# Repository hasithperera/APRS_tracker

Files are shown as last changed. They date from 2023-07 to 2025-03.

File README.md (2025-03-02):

# APRS_tracker

Standalone APRS tracker. This an Arduino-nano powered APRS tracker with a DRA818V 1 W radio module.

## Progress

- Fully functional PCB(v2) - tested up to 11 km in a HAB flight
- Basic full operation was tested with the board externally powered. Refer the test section for details.
- v3: Nearly complete PCB with new GPS module
	- level shifter externally added using a 7404 

### Firmware

- [x] Bug fix for location packets
- [x] Support for GNSS GPS (Adafruit GPS) ✅ 2024-01-28
- [x] Added support for i2c for external data sources ✅ 2024-01-28
## Testing 

In order to make sure the full functionality the generated APRS packets were tested with [direwolf](https://github.com/wb2osz/direwolf) with a RTL-SDR.
The following command was used to run the iGate

``` rtl_fm -f 144.39M - |direwolf -c sdr.conf -r 24000 -D 1 - ```

- The radio tx frequency commands were tested on a simplex 145.390 M and the standard 144.390 M
- A ground test was carried out on 05/14/23.
	- Device was powered with a external 5V USB power bank for the duration of the test
	- initial GPS lock was completed within 30 s of powering on outside.
	- It was noted that powering indoor and moving to an outdoor location increased the initial GPS lock time significantly.
	- Data collected is available online under the call sign KC3RXZ. a screenshot can be found below. Note that not all the packets were captured by the iGate and the msg_id was used as a counter for how many GPS packets were captured during the test period.Given that the iGate was located indoor and the landscape of the location could account for the lost packets.

APRS ground testing.

### Flight testing

- First HAB flight on 01/10/2023
- call: KE8TJE-11
- data: [aprs.fi](https://aprs.fi/#!mt=roadmap&z=10&call=a%2FKE8TJE-11&timerange=21600&tail=21600)
- comments: The GPS module used worked well up to 11 km of altitude. above that it was unusable
- more information available [here](https://docs.google.com/presentation/d/1fhy-rmdOGR4Q17i7Nnw9TJokxQfwU8tR1A3V_ZNNeEo/edit?usp=sharing) including flight data

## Updates to the PCB

### update: 05/07/23

- [x] Update PCB based on v1.
- know minor issues
	- jumpers on the board need to be larger

### update: October 2023

- updated the GPS module

![aprs_v3](doc/reports/res/aprs_v3.png)

### update: January 2034
- New design with an expansion slot to connect external modules.
- A DTMF decoder board is been developed.
- [ ] Final integration testing needs to be done

## Todo list 

- [x] interface GPS sensor
- [x] interface RF
- [x] APRS generation
- [x] get location and update APRS data packet
- [x] i2c slave module to provide data to master ✅ 2024-01-28
- [x] field testing 
- [x] finalized PCB design 
- [x] long range testing at altitude

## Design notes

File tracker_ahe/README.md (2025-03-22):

# APRS Tracker - customization 

Most common settings are set up as `#define` statements for easy configuration. Some of the major settings are listed below with their typical value

variable | value | note 
---| --- | --- | 
myCALL[] |  | Change to your callsign
APRS_TX_offset_utc_sec  | 19 | UTC second the packet is sent out
aprs_id | 11 | station id used for aprs

## Programming the firmware

You need to have avrdude installed on your local computer along with an USBasp programmer. 

Using arduino you can export the `hex` file by using Sketch > Export compiled Binary. A new folder `build` will be created which contains the hex file needed.
To program the APRS board use the following command. 

`avrdude -p m328p -c usbasp -U flash:w:tracker_ahe.ino.hex`

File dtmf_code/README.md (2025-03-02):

- This is an expansion board designed to be connected to the `v4` board
- Based on an ATTINY 84
- An i2c master will be running in order to sent data to the APRS board

## Audio performance 

- lab testing with 50 mW signal indicated limited functionality on the DTMF digits. Digits 7,8,9,0,#,* was confirmed to be working. a 620k is tested for the amplification
- It was noted the extended wire length induced RF and cause the signals to be unusable
	- 330 K and the build in 500 K pot was more than enough tuning range

## i2c 

- [ ] Send data to multiple addresses
- [ ] Request data from slave.  📅 2024-02-06 

## old - Docs

DTMF - Test

# To-do

- [x] i2c master sending data ✅ 2024-01-28
- [ ] i2c master reading data from slaves
- [x] Evaluate the RF/Audio performance at altitude ✅ 2024-01-29

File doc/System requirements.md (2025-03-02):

This contains the final system requirements for the system

- The user shall be able to turn on the payload
- The user shall be able to turn off the payload
- The system shall initialize the RF and GPS subsystems
- The system shall provide indicators for GPS lock,RF inputs (via DTMF)
- The system shall send location packets via APRS packets
- The system shall send DTMF, GPS time via i2c to specified slave device connected.
- The system shall burn cutdown wires upon DTMF command
- The system shall burn recovery wire at set altitude

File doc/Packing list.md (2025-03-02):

- [ ] Science payload
	- [ ] Battery 
	- [ ] Enclosure
	- [ ] Cut down string

- [ ] Recovery vehicle
	- [ ] Laptop
	- [ ] Charger
	- [ ] GPS + SDR
	- [ ] USB extension cable
	- [ ] antenna for SDR
	- [ ] Emmcomm kit for radio
	- [ ] Adapters for antennas 
	- [ ] HT - for low power testing 

## Testing to be done and time line

- [ ] Full cut-down testing in lab. verify pin `789`
- [ ] Confirm data write to SD card
	- [ ] i2c command log
	- [ ] GPS data log

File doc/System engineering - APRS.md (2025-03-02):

# APRS payload - Concept

 ## Need
- To track rockets during descent and help recovery by identifying the location after landing

## Stake holders
- Rocketry control system 
- FCC 
- Additions due to NEBP
	- NEBP & WVBEAR -  (Added as an alternate user after the initial design)
	- FAA
	- Science Payload (Addition after PAGSO grant acceptance)

---
## Constraints 

- Weight:
	- Based on the specification of NEBP payload design 350 g
- Physical Dimensions:
	- need to be able to fit inside a 3.5 inch rocket. 
	- Have a thermal insulation (High altitude use - NEBP)
- Operational altitude
	- 10 km - from Rocketry
	- 30 km - from NEBP HAB requirements 
- Power -  5v (2s Li-ion/Li-Po)
- Standalone and paired operation modes
- FCC requirements: [47 CFR 97.307(e)](https://www.ecfr.gov/current/title-47/part-97#p-97.307(e))
	- data down link. (uplink added as a Science requirement)

---
# Use case diagram - Rocketry

UML_1

---
# Use case diagram - NEBP

UML_2

---

# Use case diagram - NEBP + Science

UML_3

---
# Logical architecture 

logical

---
## Interface specifications

- RF IF
	- **Data down link:** 144.390 MHz AX 2.5 encoded data stream every 5 mins
		- Have a secondary frequency for high cadence data 
	- **Up link**: some random frequency for each payload using DTMF commands
- i2c IF
	- DTMF and GPS time data will be sent to slave devices
		- Commands:  upto 20 digits can be stored and sent as a single char array. shorter commands can be defined using the `#` as the termination char.
		- GPS time: 3 8 bit integers containing hh,mm,ss in that order
---
## Interface specifications - 2

- Physical IF
	- the payload will be physically connected to the flight line with **Micro code** up to a length of 1 ft.
	- These will be routed through a burn wire
- Power IF
	- 7.4 V Li-Ion cells
	- a shared 5 V regulated supply up to 800 mA

---
# Final system requirements

- The user shall be able to turn on the payload
- The user shall be able to turn off the payload
- The system shall initialize the RF and GPS subsystems
- The system shall provide indicators for GPS lock,RF inputs (via DTMF)
- The system shall send location packets via APRS packets
- The system shall send DTMF, GPS time via i2c to specified slave device connected.
- The system shall burn cutdown wires upon DTMF command
- The system shall burn recovery wire at set altitude

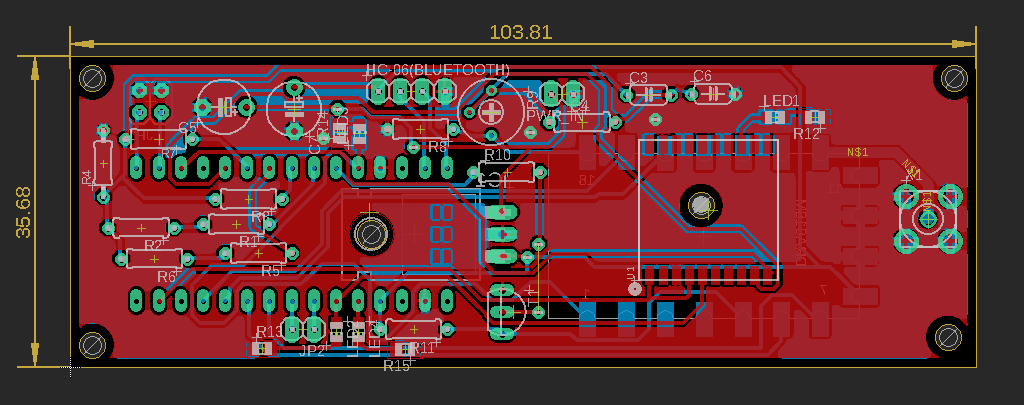
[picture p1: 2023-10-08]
doc/reports/res/aprs_v3.png

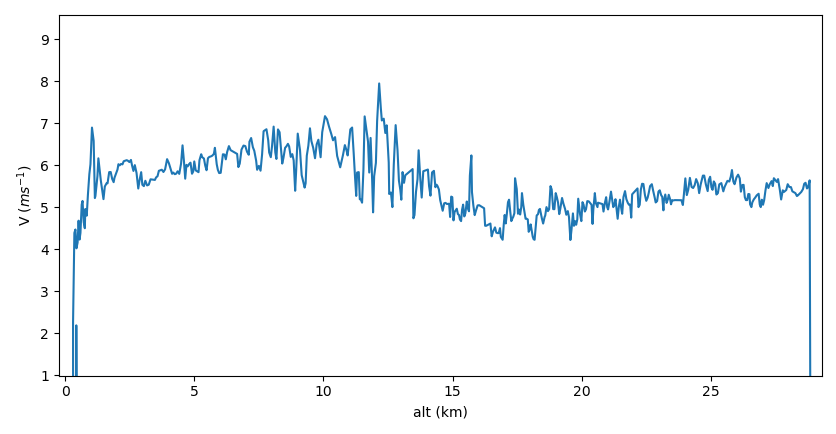
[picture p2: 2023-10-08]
doc/reports/res/v_alt_NEBP2.png

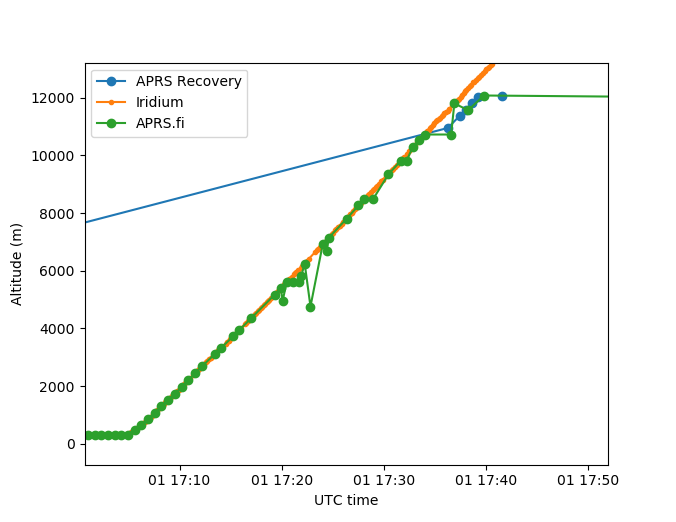
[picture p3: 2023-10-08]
doc/reports/res/01_10_23_altitude_ascent_data.png

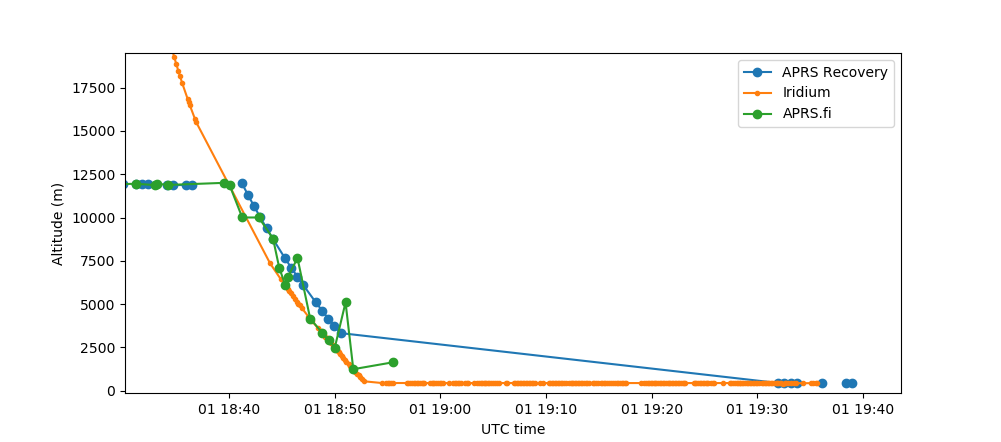
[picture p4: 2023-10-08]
doc/reports/res/01_10_23_altitude_dsc_data.png

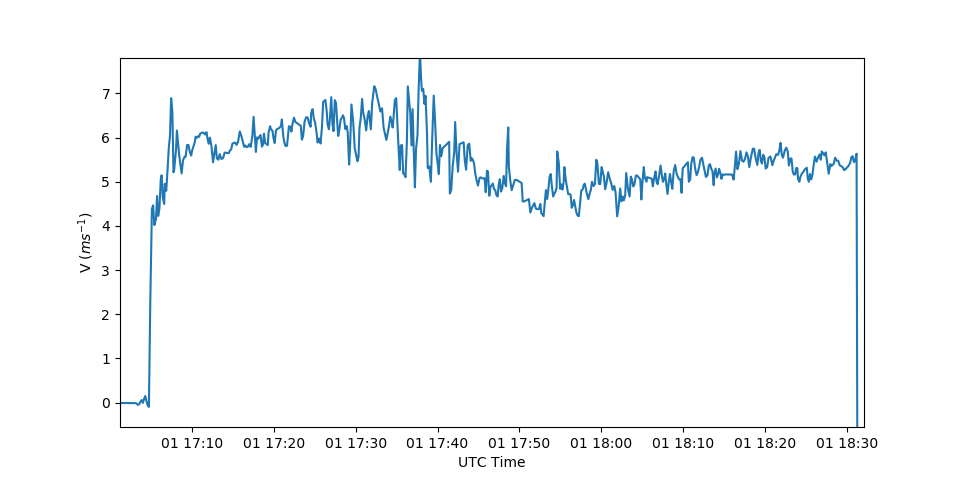
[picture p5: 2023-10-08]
doc/reports/res/v_t_NEBP2.png

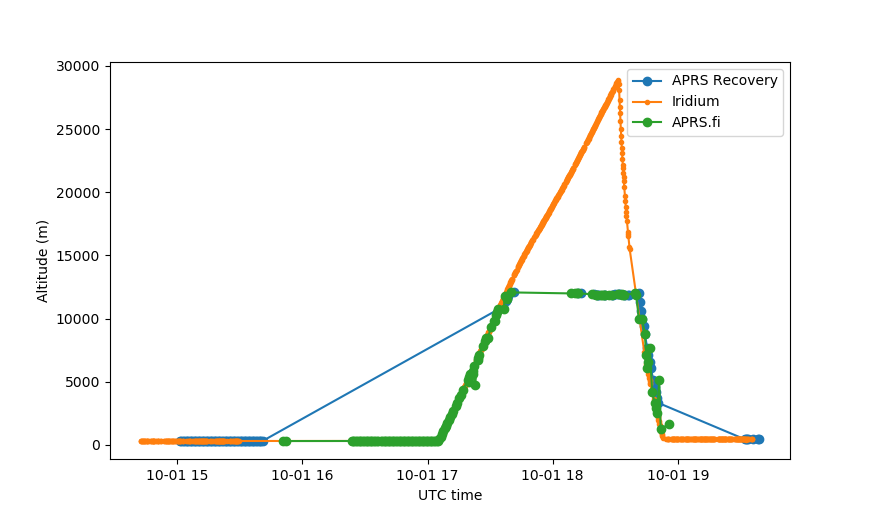
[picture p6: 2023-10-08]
doc/reports/res/01_10_23_altitude_data.png

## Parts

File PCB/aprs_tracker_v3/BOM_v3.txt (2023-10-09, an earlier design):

Partlist

Exported from aprs_tracker_v3.brd at 10/9/23 8:44 AM

EAGLE Version 9.6.2 Copyright (c) 1988-2020 Autodesk, Inc.

Assembly variant: 

Part             Value          Package       Library       Position (mil)        Orientation

C3               4.7u           C050-024X044  rcl           (2610 1230)           R0
C4               4.7u           C1206         rcl           (2609.37008 1325)     R0
C5               10u            E5-6          rcl           (695 1175)            R180
C6               100n           C050-024X044  rcl           (2900 1235)           R0
C7               10u            E5-6          rcl           (1010 1165)           R270
HC-06(BLUETOOTH)                1X04          pinhead       (1540 1245)           R0
IC1              7805T          TO220H        adafruit      (1550 600)            MR270
JP1                             2X02          pinhead       (360 1200)            MR180
JP2                             1X02          pinhead       (1050 170)            R180
LED1                            CHIP-LED0805  led           (3180 1130)           R270
LED2                            CHIP-LED0805  led           (1200 160)            R180
LED3                            CHIP-LED0805  led           (1305 1055)           R0
LED4                            CHIP-LED0805  led           (1300 160)            R180
PWR_IN                          1X02          pinhead       (2259.37008 1235)     R180
R1               6.2k           0207/7        rcl           (750 645)             R180
R2               2k             0207/7        rcl           (320 630)             R180
R3               3.9k           0207/7        rcl           (805 760)             R180
R4               270            0204/7        rcl           (150 920)             R90
R5               1.2k           0207/7        rcl           (850 515)             R180
R6               1k             0207/7        rcl           (380 490)             R180
R7               1k             0207/7        rcl           (400 1030)            R180
R8               1k             0207/7        rcl           (1580 1075)           R180
R9               1k             RTRIM3339P    rcl           (1930 1160)           R270
R10              1k             0207/7        rcl           (1970 880)            R0
R11              1k             0207/7        rcl           (1550 170)            R180
R12              330            R0805         rcl           (3360 1130)           R180
R13              330            R0805         rcl           (865 85)              R0
R14              330            R0805         rcl           (1215 1060)           R90
R15              330            R0805         rcl           (1510 80)             R180
T1               2N2222         TO92-EBC-OVAL adafruit      (2000 250)            R270
U$1                             DRA818A       dorji         (2855 590)            MR90
U$4              NANO-2         NANO-NOICSP   Arduino-clone (1350 700)            R90
U1                              FGPMMOPA6H    adafruit      (2880 710)            R90
X1               BU-SMA-V       BU-SMA-V      con-coax      (3870 670)            R0

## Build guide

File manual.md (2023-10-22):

# Offline ground station and Tracker manual

## Tracker configuration 

- current configuration: These settings needs to be set by reprogramming and current settings are indicated 
	- call sign: KE8TJE-11
  - beacon time: ~40 

internally on the PCB there are two configuration pins available for testing

- pin 1: frequency selection (0: 144.390 M 1: 145.390 M) 
- pin 2: location data (1: sim data 0: GPS data)

## Ground station configuration

- Run `rtl-test` to check if the SDR is working 
- `rtl_fm -f 144.39M - |direwolf -c sdr.conf -r 24000 -D 1 - >> log_sdr.log`
- run for visualization `java -jar YAAC.jar`

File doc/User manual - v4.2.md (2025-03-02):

- Use `v4.2` this is found in the `dtmf` branch on the repository.
## Confirm APRS opetation

- By default this is design for a ~30 s update rate on the 144.390 MHz standard APRS frequency in the US.
- There are two use configurable jumpers available for testing:
	
	- JP1 can be used to change the frequency to an alternate frequency.
	- JP2 can be used to enable simulation mode. This allows indoor testing on the module without GPS lock

- Onboard LEDs
	- D1: GPS serial Rx
	- D2: GPS serial Tx
	- D3: 3D GPS lock
	- D4: RF channel busy indicator active low. (Rx frequency is set to 146.800 MHz)
	- D5: Power indicator
### Simulation mode

- Connect a jumper to JP2. This will populate GPS data with a valid data packet located in Morgantown WV. (location ) verify the APRS data is correctly encoded in your preferred decoding software

### Debug data via serial terminal

- In addition to readable status comment the `$GNGGA` packets are redirected to the serial terminal when not in simulation mode
- When there is GPS lock decoded Longitude and Latitude is made available to the user.
	- `3938.76N,07958.44W`
- Sample terminal out put during simulation mode
  
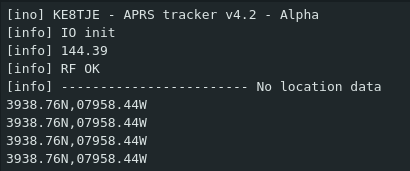
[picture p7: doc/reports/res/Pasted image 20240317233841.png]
	

## DTMF commanding

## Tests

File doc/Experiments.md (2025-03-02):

## OTA
- 57600 BAUD did not seem to work to program the arduino.
- It could be due 
	- reset pin not being correctly configured with the voltage levels
	- baud rate used may not be correct 

## Ground testing - v4

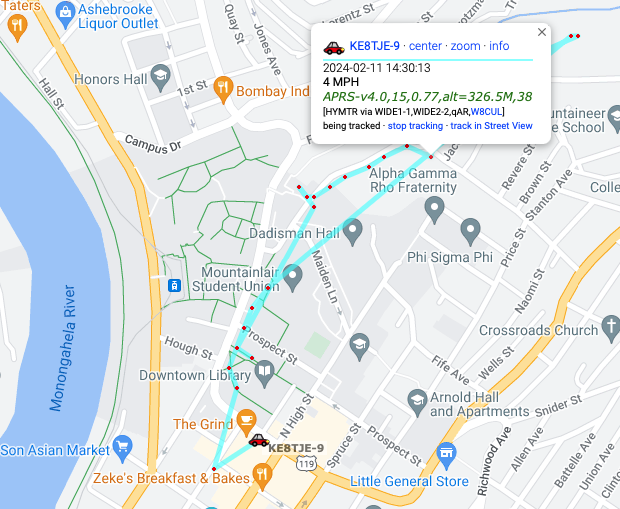
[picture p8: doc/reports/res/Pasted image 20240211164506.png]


- Ground testing was done on low power 50 mW, wired antenna. Packets were detected by W8CUL.
- GPS lock was stable. BT module was powered off automatically without reason. needs to be investigated.

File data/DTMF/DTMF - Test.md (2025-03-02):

To make this platform capable of using DTMF commands the audio from the radio (DRA818v) needs to be processed. 

### 23/12/2023

- Initial experiments done before failed since the induced RF was too strong to measure the output signal. a VOX base remote transmitting radio was used to isolate the induced RF
- SQL signal was used to trigger the scope.
	
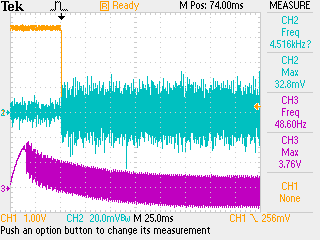
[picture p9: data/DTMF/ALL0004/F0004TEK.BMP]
F0004TEK
	
	- Yellow -  SQL signal from the radio
	- Blue - Audio output from the radio (1500 Hz tone playing) 
	- Purple - Audio output from FT530 (standard radio)
- DTMF tones - 0,1,3 
	
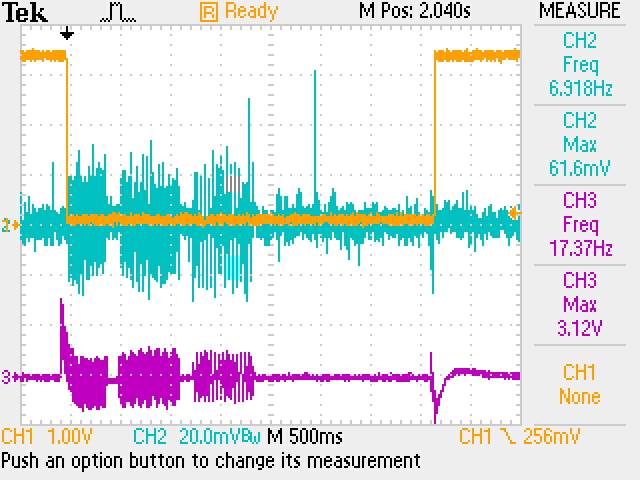
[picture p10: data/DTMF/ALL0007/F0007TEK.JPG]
F0007TEK| 320
	
- tones are generated using audacity
- **This was audible using a head phone.** It might work without any modifications

### 24/12/2023

- a gain of 4 on the pre-amp worked out well from lab testing. It would be better to add a pot to have a rage of gain we can tune on the final board 
- use a Attiny84 to send commands to the radio 
- StD pin should be mounted as an interrupt pin on the attiny  

### 25/12/2023

Interface pin list between APRS and DTMF boards
 - 5 v
 - 3.3 v
 - GND x 2
 - Battery in
 - Audio  in 
 - i2c pins - (SCL/SDA)
 - optional x 2 for future use - Potentially to kill the PhaT module after landing
	Total of 10 pins. 5x2 connector specification as shown below

### 05/01/2024

- Finalized the PCB design and generated outputs compatible with JLC
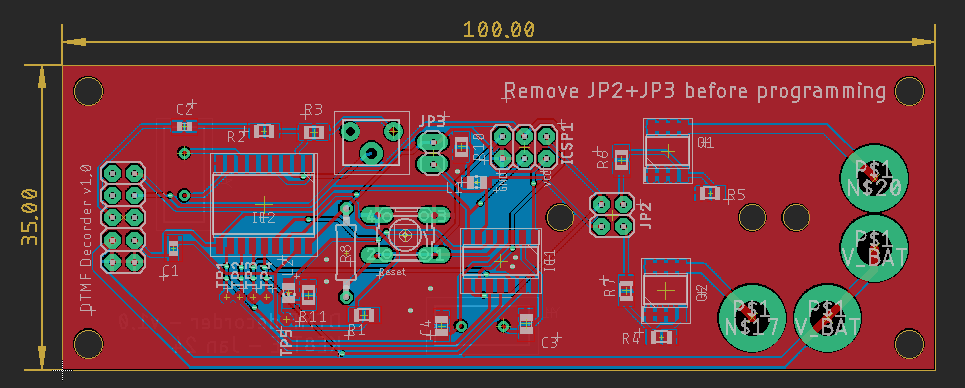
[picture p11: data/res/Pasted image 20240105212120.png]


# 27/01/2024

- Tested tone detection with the attiny 84. 4.7 M resister was replaced on R3 for amplification.
- Indoor testing showed working DTMF decording working on the 1st floor of the building 
### Todo

- [x] Test a schematic for MT8870
- [x] PCB design ✅ 2024-01-05

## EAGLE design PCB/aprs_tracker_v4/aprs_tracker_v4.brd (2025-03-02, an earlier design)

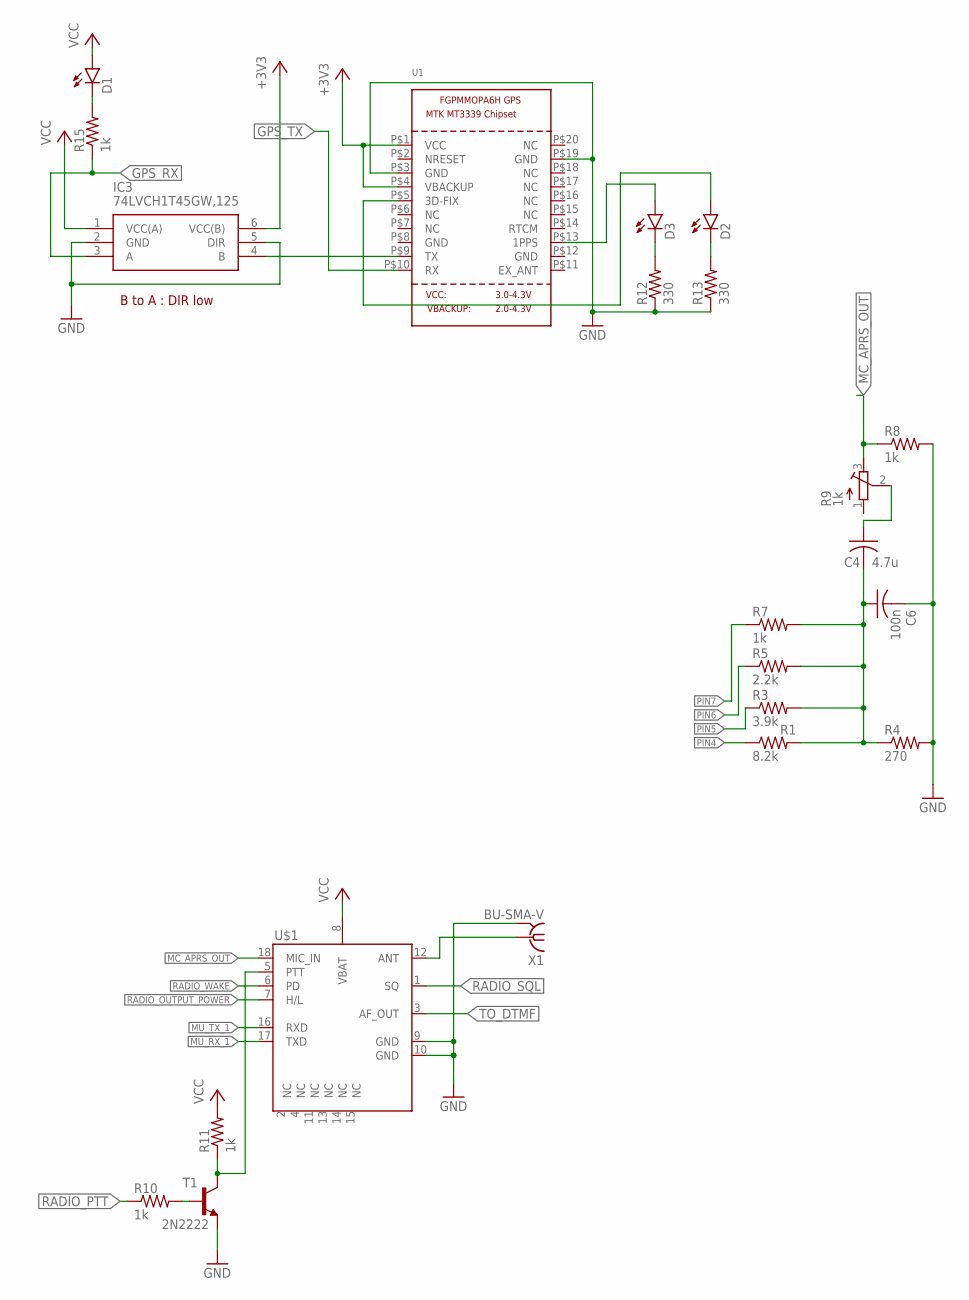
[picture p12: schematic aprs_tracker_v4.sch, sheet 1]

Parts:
C4: 4.7u; C0805
C6: 100n; C0805
D1, D2, D3: LEDCHIP-LED0805; CHIP-LED0805
IC3: 74LVCH1T45GW,125; 74LVCH1T45GW125
R1: 8.2k; R0805
R3: 3.9k; R0805
R4: 270; R0805
R5: 2.2k; R0805
R7, R8, R10, R11, R15: 1k; R0805
R9: 1k; RTRIM3339P
R12, R13: 330; R0805
T1: 2N2222; TO92-EBC-OVAL
U1: GPS_FGPMMOPA6H; FGPMMOPA6H
U$1: DRA818A
X1: BU-SMA-V

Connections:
+3V3: IC3.6 (VCC(B)), U1.P$1 (VCC), U1.P$4 (VBACKUP); also elsewhere on the board
A63: D2.A, U1.P$5 (3D-FIX)
GND: C6.2, IC3.2 (GND), IC3.5 (DIR), R4.2, R8.2, R12.1, R13.1, T1.E, U1.P$3 (GND), U1.P$19 (GND), U$1.9 (GND), U$1.10 (GND), X1.2, X1.3 (2), X1.4 (2), X1.5 (2); also elsewhere on the board
GPS_RX: IC3.3 (A), R15.1; also elsewhere on the board
GPS_TX: U1.P$10 (RX); also elsewhere on the board
MC_APRS_OUT: R8.1, R9.3 (E), U$1.18 (MIC_IN)
MU_RX_1: U$1.17 (TXD); also elsewhere on the board
MU_TX_1: U$1.16 (RXD); also elsewhere on the board
unnamed: U$1.12 (ANT), X1.1
unnamed: D1.C, R15.2
unnamed: IC3.4 (B), U1.P$9 (TX)
unnamed: C4.2, C6.1, R1.2, R3.2, R4.1, R5.2, R7.2
unnamed: C4.1, R9.2 (S)
unnamed: R11.1, T1.C, U$1.5 (PTT)
unnamed: R10.2, T1.B
unnamed: D3.C, R12.2
unnamed: D2.C, R13.2
unnamed: D3.A, U1.P$13 (1PPS)
PIN4: R1.1; also elsewhere on the board
PIN5: R3.1; also elsewhere on the board
PIN6: R5.1; also elsewhere on the board
PIN7: R7.1; also elsewhere on the board
RADIO_OUTPUT_POWER: U$1.7 (H/L); also elsewhere on the board
RADIO_PTT: R10.1; also elsewhere on the board
RADIO_SQL: U$1.1 (SQ); also elsewhere on the board
RADIO_WAKE: U$1.6 (PD); also elsewhere on the board
TO_DTMF: U$1.3 (AF_OUT); also elsewhere on the board
VCC: D1.A, IC3.1 (VCC(A)), R11.2, U$1.8 (VBAT); also elsewhere on the board

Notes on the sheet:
B to A : DIR low

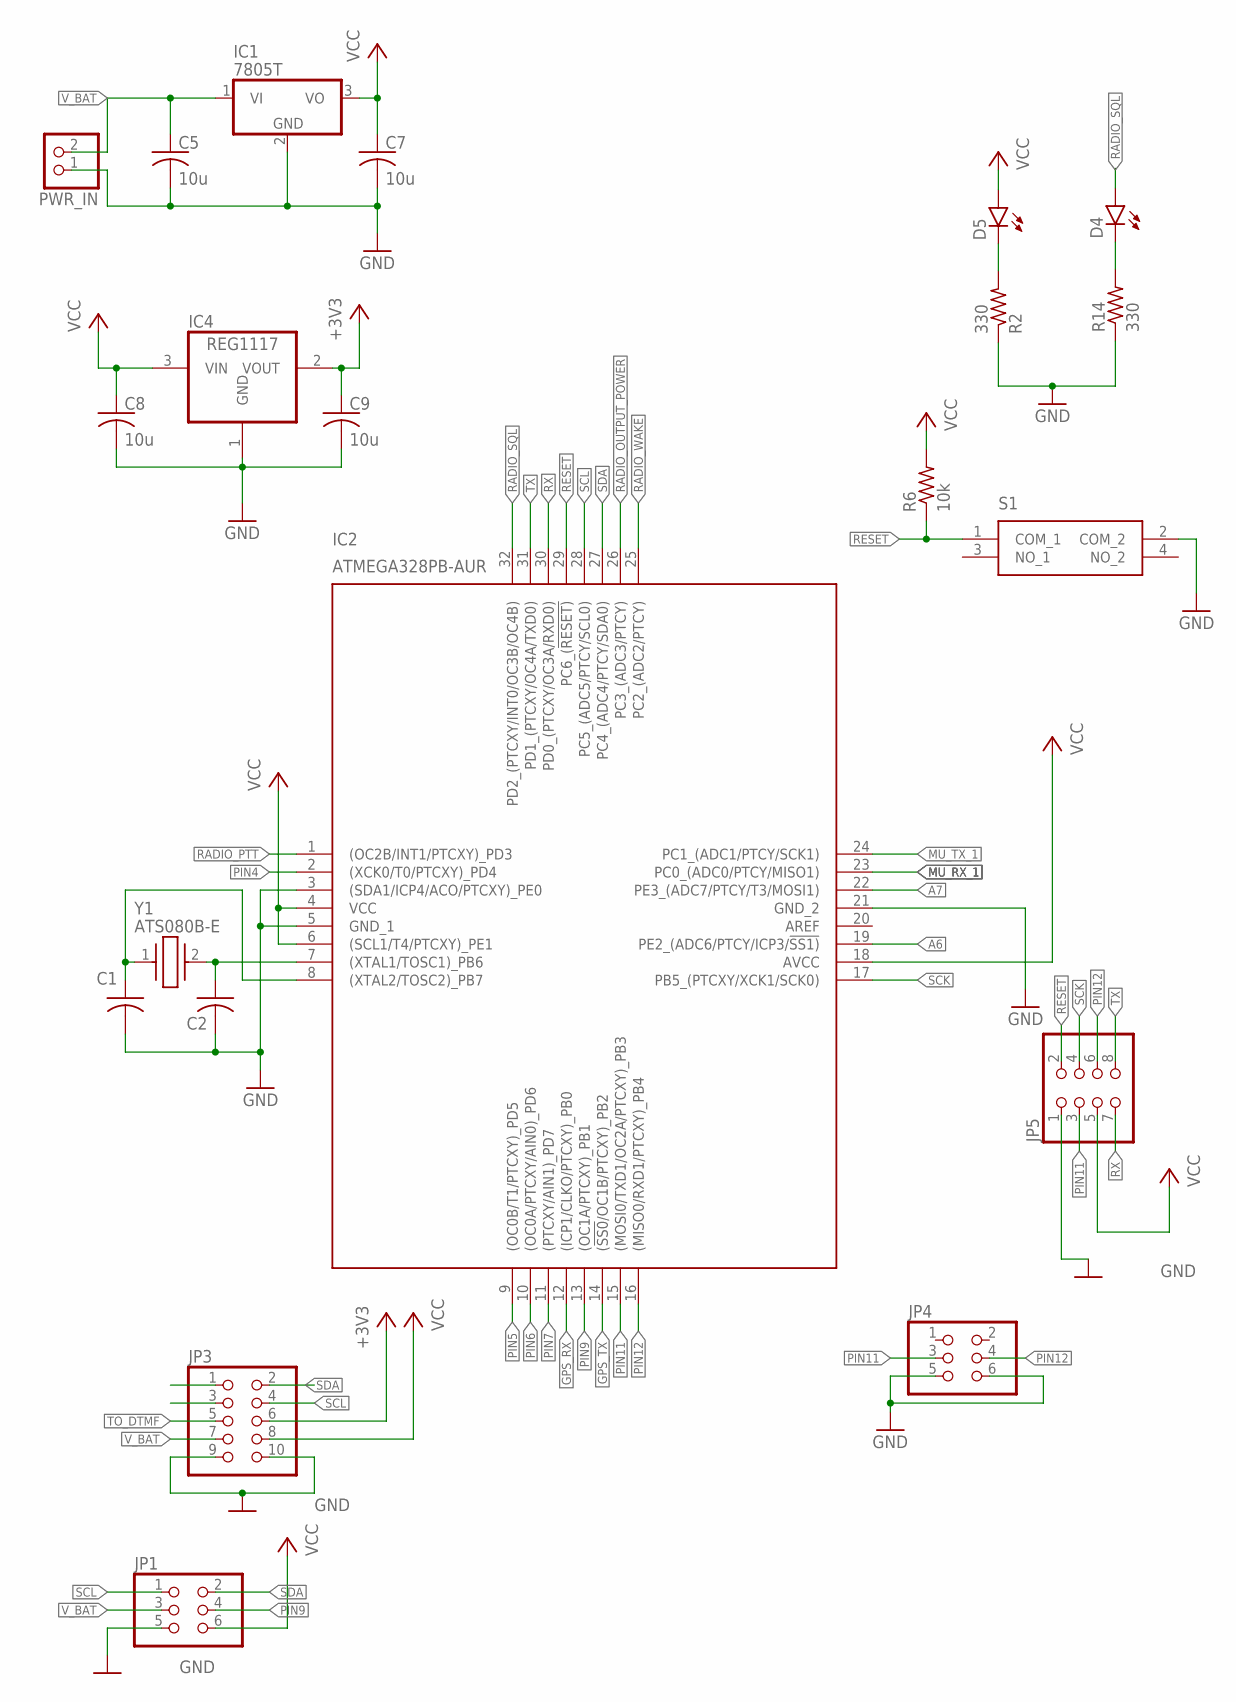
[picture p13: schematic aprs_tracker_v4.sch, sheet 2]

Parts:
C1, C2: C-USC0805; C0805
C5, C7, C8, C9: 10u; C0805
D4, D5: LEDCHIP-LED0805; CHIP-LED0805
IC1: 7805T; TO220H
IC2: ATMEGA328PB-AUR; QFP80P900X900X120-32N
IC4: REG1117; SOT223
JP1, JP4: PINHD-2X3/90; 2X03/90
JP3: PINHD-2X5; 2X05
JP5: PINHD-2X4; 2X04
PWR_IN: PINHD-1X2/90; 1X02/90
R2, R14: 330; R0805
R6: 10k; R0805
S1: PTS526_SK15_SMTR2_LFS; PTS526SK15SMTR2LFS
Y1: ATS080B-E; ATS080BE

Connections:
+3V3: C9.1, IC4.2 (VOUT), JP3.6; also elsewhere on the board
A6: IC2.19 (PE2_(ADC6/PTCY/ICP3/!SS1))
A7: IC2.22 (PE3_(ADC7/PTCY/T3/MOSI1))
GND: C1.2, C2.2, C5.2, C7.2, C8.2, C9.2, IC1.2 (GND), IC2.3 ((SDA1/ICP4/ACO/PTCXY)_PE0), IC2.5 (GND_1), IC2.21 (GND_2), IC4.1 (GND), JP1.5, JP3.9, JP3.10, JP4.5, JP4.6, JP5.1, PWR_IN.1, R2.1, R14.1, S1.2 (COM_2); also elsewhere on the board
GPS_RX: IC2.12 ((ICP1/CLKO/PTCXY)_PB0); also elsewhere on the board
GPS_TX: IC2.14 ((!SS0!/OC1B/PTCXY)_PB2); also elsewhere on the board
MU_RX_1: IC2.23 (PC0_(ADC0/PTCY/MISO1)); also elsewhere on the board
MU_TX_1: IC2.24 (PC1_(ADC1/PTCY/SCK1)); also elsewhere on the board
unnamed: D5.C, R2.2
unnamed: C1.1, IC2.8 ((XTAL2/TOSC2)_PB7), Y1.1
unnamed: C2.1, IC2.7 ((XTAL1/TOSC1)_PB6), Y1.2
unnamed: D4.C, R14.2
PIN4: IC2.2 ((XCK0/T0/PTCXY)_PD4); also elsewhere on the board
PIN5: IC2.9 ((OC0B/T1/PTCXY)_PD5); also elsewhere on the board
PIN6: IC2.10 ((OC0A/PTCXY/AIN0)_PD6); also elsewhere on the board
PIN7: IC2.11 ((PTCXY/AIN1)_PD7); also elsewhere on the board
PIN9: IC2.13 ((OC1A/PTCXY)_PB1), JP1.4
PIN11: IC2.15 ((MOSI0/TXD1/OC2A/PTCXY)_PB3), JP4.3, JP5.3
PIN12: IC2.16 ((MISO0/RXD1/PTCXY)_PB4), JP4.4, JP5.6
RADIO_OUTPUT_POWER: IC2.26 (PC3_(ADC3/PTCY)); also elsewhere on the board
RADIO_PTT: IC2.1 ((OC2B/INT1/PTCXY)_PD3); also elsewhere on the board
RADIO_SQL: D4.A, IC2.32 (PD2_(PTCXY/INT0/OC3B/OC4B)); also elsewhere on the board
RADIO_WAKE: IC2.25 (PC2_(ADC2/PTCY)); also elsewhere on the board
RESET: IC2.29 (PC6_(!RESET)), JP5.2, R6.1, S1.1 (COM_1)
RX: IC2.30 (PD0_(PTCXY/OC3A/RXD0)), JP5.7
SCK: IC2.17 (PB5_(PTCXY/XCK1/SCK0)), JP5.4
SCL: IC2.28 (PC5_(ADC5/PTCY/SCL0)), JP1.1, JP3.4
SDA: IC2.27 (PC4_(ADC4/PTCY/SDA0)), JP1.2, JP3.2
TO_DTMF: JP3.5; also elsewhere on the board
TX: IC2.31 (PD1_(PTCXY/OC4A/TXD0)), JP5.8
VCC: C7.1, C8.1, D5.A, IC1.3 (VO), IC2.4 (VCC), IC2.6 ((SCL1/T4/PTCXY)_PE1), IC2.18 (AVCC), IC4.3 (VIN), JP1.6, JP3.8, JP5.5, R6.2; also elsewhere on the board
V_BAT: C5.1, IC1.1 (VI), JP1.3, JP3.7, PWR_IN.2

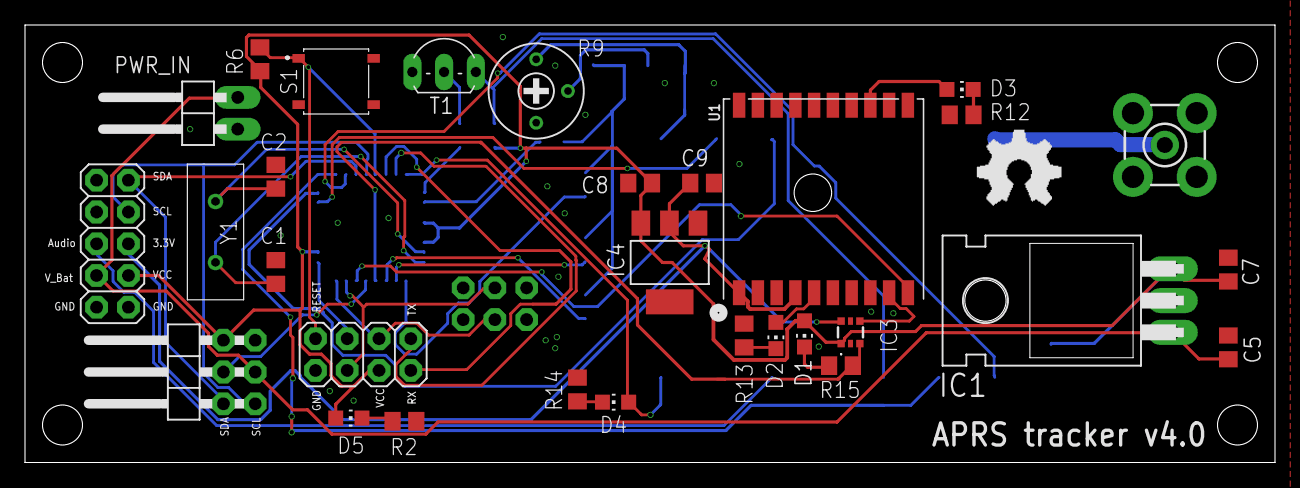
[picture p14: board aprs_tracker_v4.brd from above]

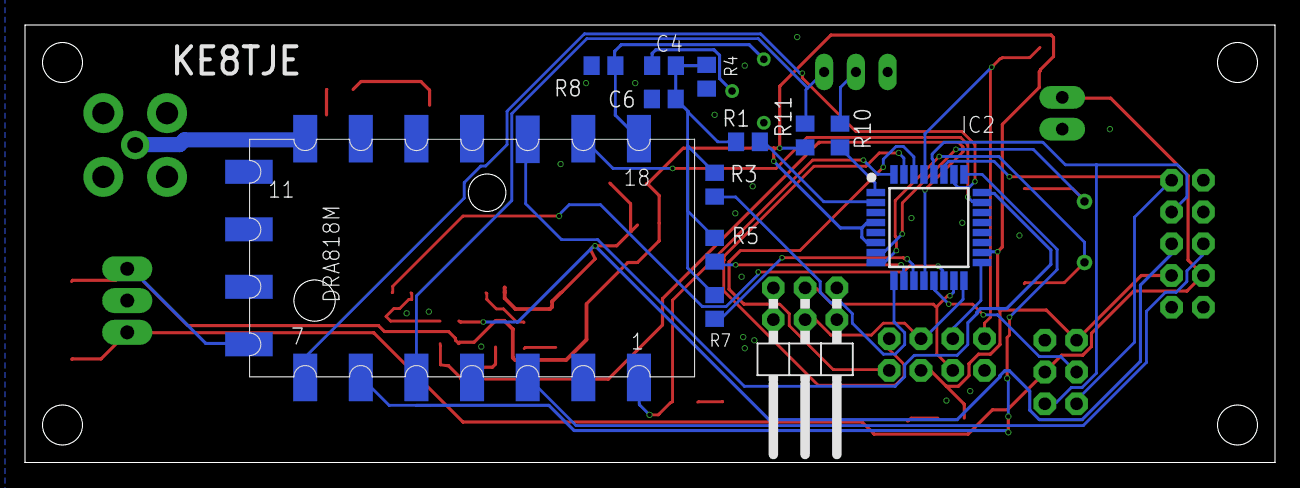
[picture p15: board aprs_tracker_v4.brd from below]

Board: 2 copper layers, 100.0 x 35.0 mm, 43 parts (13 on the bottom side), 42 nets.

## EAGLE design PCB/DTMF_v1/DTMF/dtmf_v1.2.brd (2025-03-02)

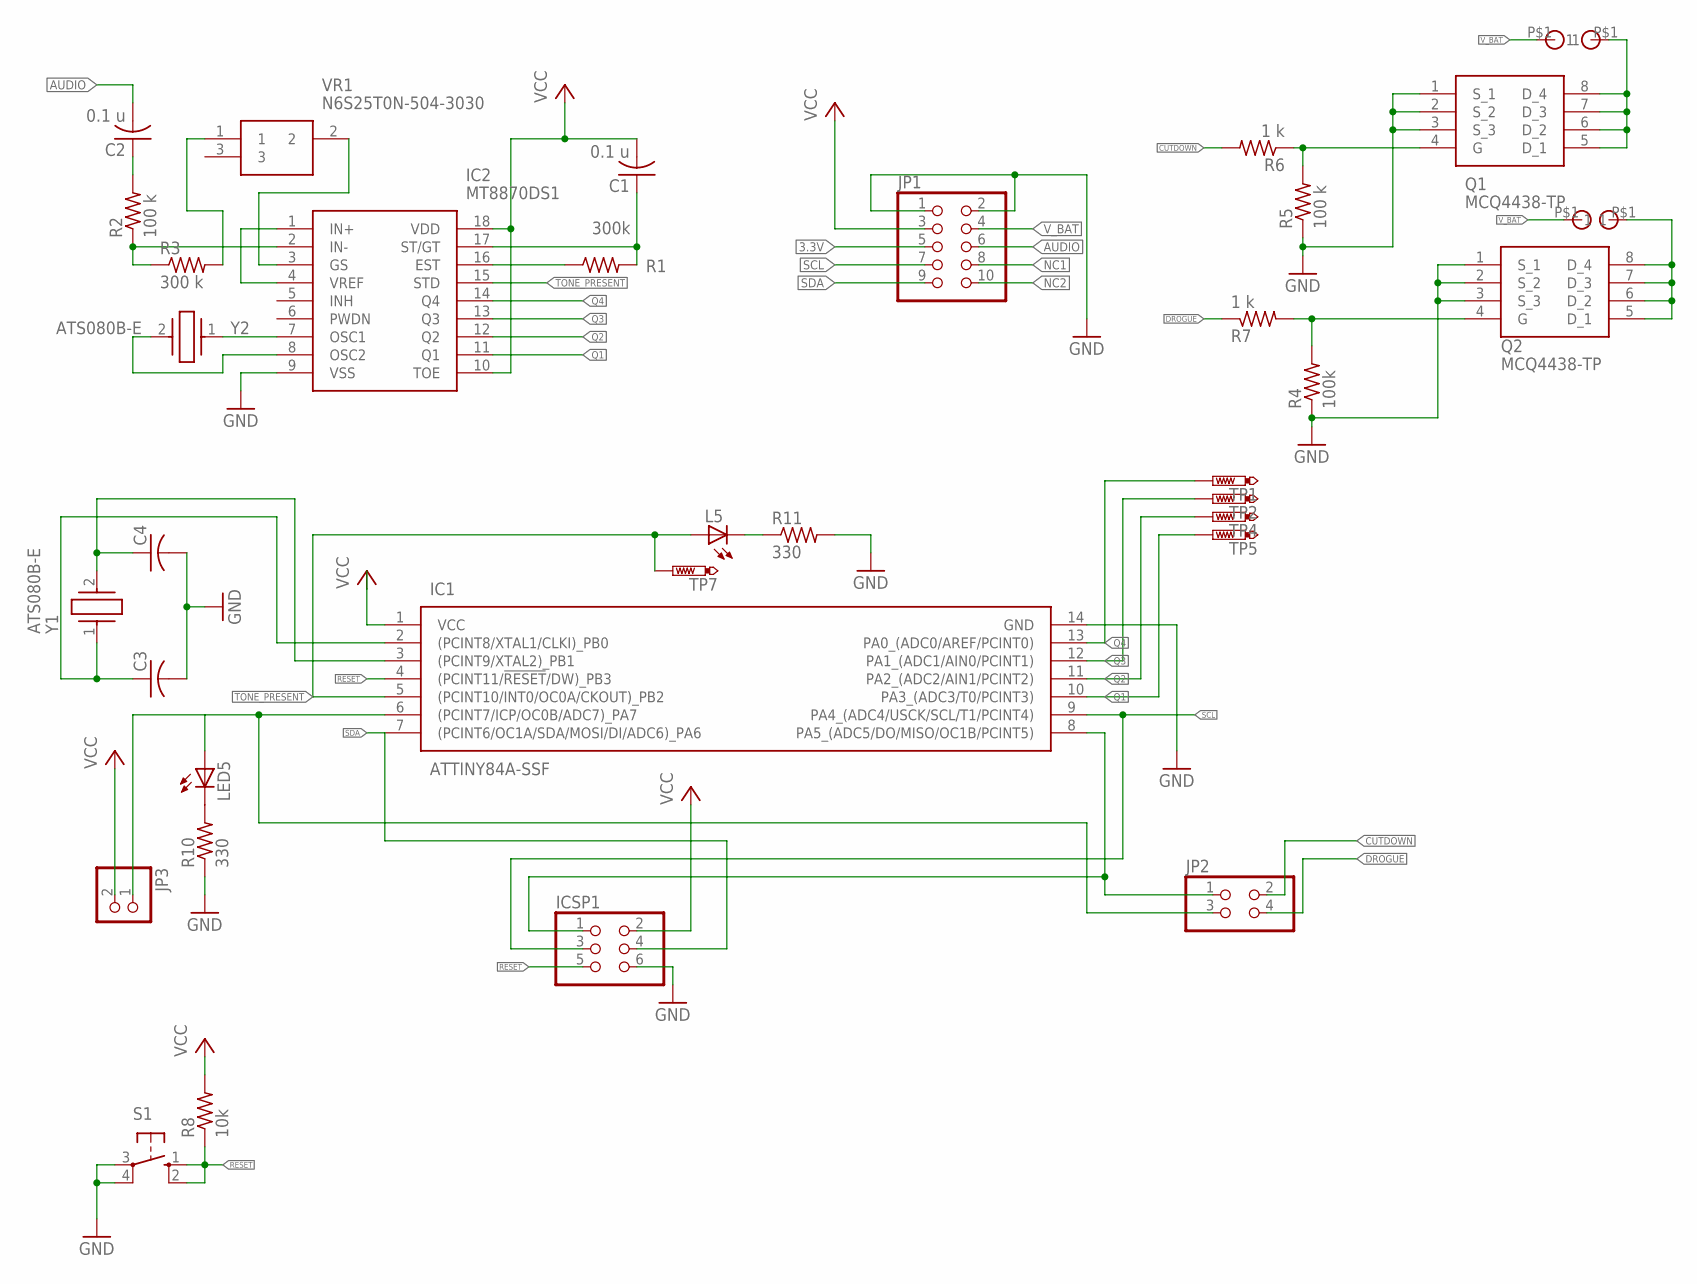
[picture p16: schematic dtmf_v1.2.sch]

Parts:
C1, C2: 0.1 u; C0603
C3, C4: C-USC0805; C0805
IC1: ATTINY84A-SSF; SOIC127P600X175-14N
IC2: MT8870DS1; SOIC127P1032X265-18N
ICSP1: PINHD-2X3; 2X03
JP1: PINHD-2X5; 2X05
JP2: PINHD-2X2; 2X02
JP3: PINHD-1X2; 1X02
L5: LEDCHIP-LED0805; CHIP-LED0805
LED5: LEDCHIP-LED0805; CHIP-LED0805
Q1, Q2: MCQ4438-TP; SOIC127P600X175-8N
R1: 300k; M0805
R2, R5: 100 k; M0805
R3: 300 k; M0805
R4: 100k; M0805
R6, R7: 1 k; M0805
R8: 10k; 0207/10
R10, R11: 330; M0805
S1: 10-XX; B3F-10XX
TP1, TP2, TP4, TP5, TP7: PTR1B1,27; B1,27
U$1, U$2, U$3, U$4: M3_HOLE; MOUNTING_PAD
VR1: N6S25T0N-504-3030; N6S25T0N5043030
Y1, Y2: ATS080B-E; ATS080BE

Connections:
3.3V: JP1.5
AUDIO: C2.2, JP1.6
CUTDOWN: JP2.2, R6.2
DROGUE: JP2.4, R7.1
GND: C3.2, C4.2, IC1.14 (GND), IC2.9 (VSS), ICSP1.6, JP1.1, JP1.2, Q1.1 (S_1), Q1.2 (S_2), Q1.3 (S_3), Q2.1 (S_1), Q2.2 (S_2), Q2.3 (S_3), R4.1, R5.1, R10.1, R11.2, S1.3, S1.4 (P1)
unnamed: IC2.7 (OSC1), Y2.1
unnamed: IC2.8 (OSC2), Y2.2
unnamed: IC2.1 (IN+), IC2.4 (VREF)
unnamed: Q1.4 (G), R5.2, R6.1
unnamed: C3.1, IC1.2 ((PCINT8/XTAL1/CLKI)_PB0), Y1.1
unnamed: C4.1, IC1.3 ((PCINT9/XTAL2)_PB1), Y1.2
unnamed: C1.1, IC2.17 (ST/GT), R1.2
unnamed: IC2.16 (EST), R1.1
unnamed: R3.2, VR1.1
unnamed: IC2.2 (IN-), R2.1, R3.1
unnamed: C2.1, R2.2
unnamed: IC2.3 (GS), VR1.2
unnamed: Q2.5 (D_1), Q2.6 (D_2), Q2.7 (D_3), Q2.8 (D_4), U$4.P$1
unnamed: Q1.5 (D_1), Q1.6 (D_2), Q1.7 (D_3), Q1.8 (D_4), U$2.P$1
unnamed: IC1.6 ((PCINT7/ICP/OC0B/ADC7)_PA7), JP2.3, JP3.1, LED5.A
unnamed: LED5.C, R10.2
unnamed: IC1.8 (PA5_(ADC5/DO/MISO/OC1B/PCINT5)), ICSP1.1, JP2.1
unnamed: L5.C, R11.1
unnamed: Q2.4 (G), R4.2, R7.2
NC1: JP1.8
NC2: JP1.10
Q1: IC1.10 (PA3_(ADC3/T0/PCINT3)), IC2.11 (Q1), TP5.TP
Q2: IC1.11 (PA2_(ADC2/AIN1/PCINT2)), IC2.12 (Q2), TP4.TP
Q3: IC1.12 (PA1_(ADC1/AIN0/PCINT1)), IC2.13 (Q3), TP2.TP
Q4: IC1.13 (PA0_(ADC0/AREF/PCINT0)), IC2.14 (Q4), TP1.TP
RESET: IC1.4 ((PCINT11/!RESET!/DW)_PB3), ICSP1.5, R8.1, S1.1 (S), S1.2 (S1)
SCL: IC1.9 (PA4_(ADC4/USCK/SCL/T1/PCINT4)), ICSP1.3, JP1.7
SDA: IC1.7 ((PCINT6/OC1A/SDA/MOSI/DI/ADC6)_PA6), ICSP1.4, JP1.9
TONE_PRESENT: IC1.5 ((PCINT10/INT0/OC0A/CKOUT)_PB2), IC2.15 (STD), L5.A, TP7.TP
VCC: C1.2, IC1.1 (VCC), IC2.10 (TOE), IC2.18 (VDD), ICSP1.2, JP1.3, JP3.2, R8.2
V_BAT: JP1.4, U$1.P$1, U$3.P$1

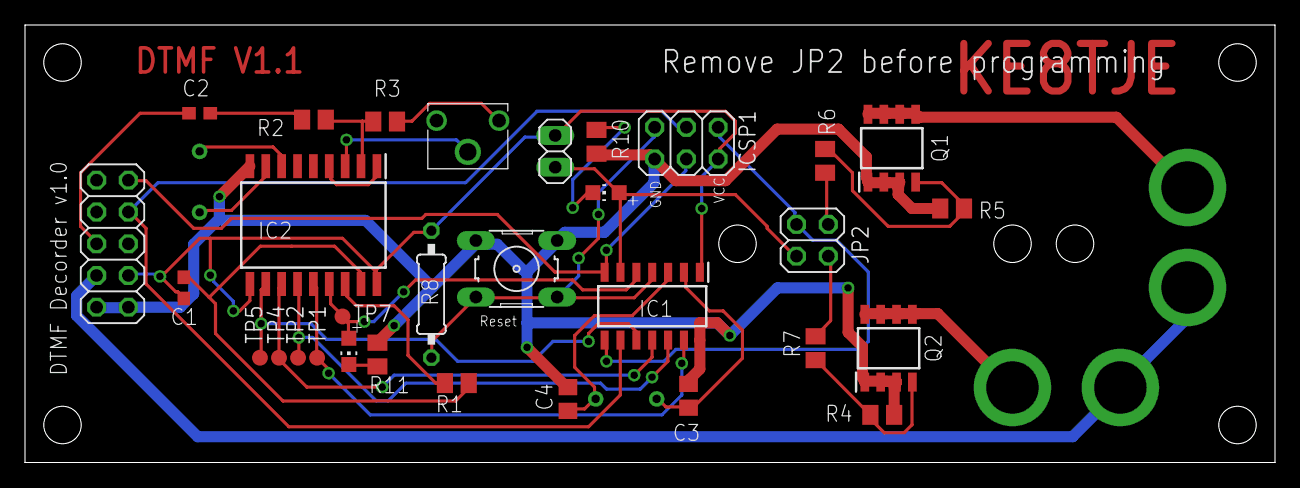
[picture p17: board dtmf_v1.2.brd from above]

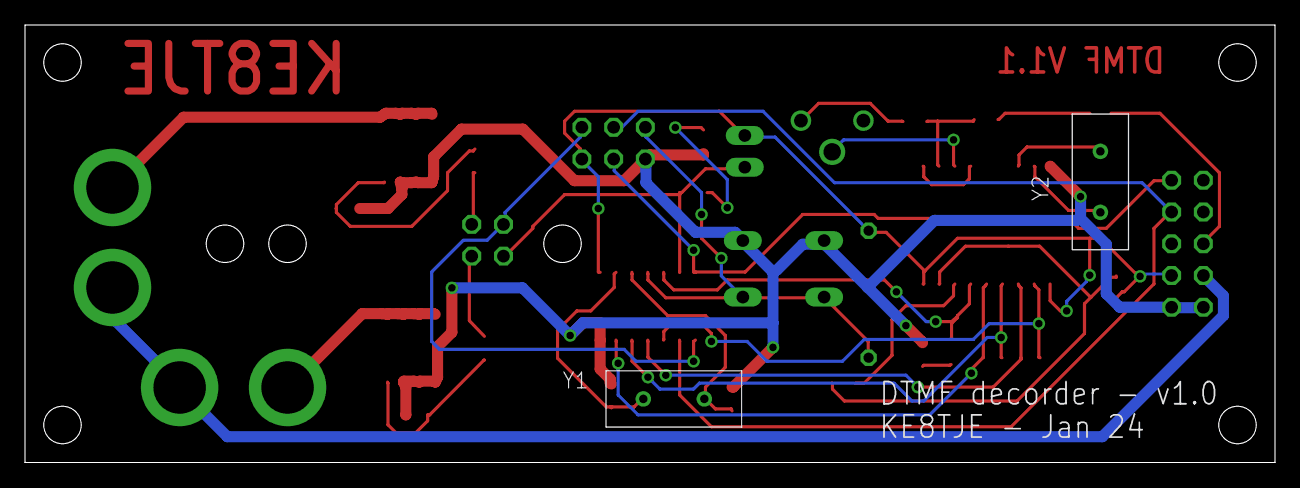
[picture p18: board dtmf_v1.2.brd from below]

Board: 2 copper layers, 100.0 x 35.0 mm, 37 parts (2 on the bottom side), 33 nets.

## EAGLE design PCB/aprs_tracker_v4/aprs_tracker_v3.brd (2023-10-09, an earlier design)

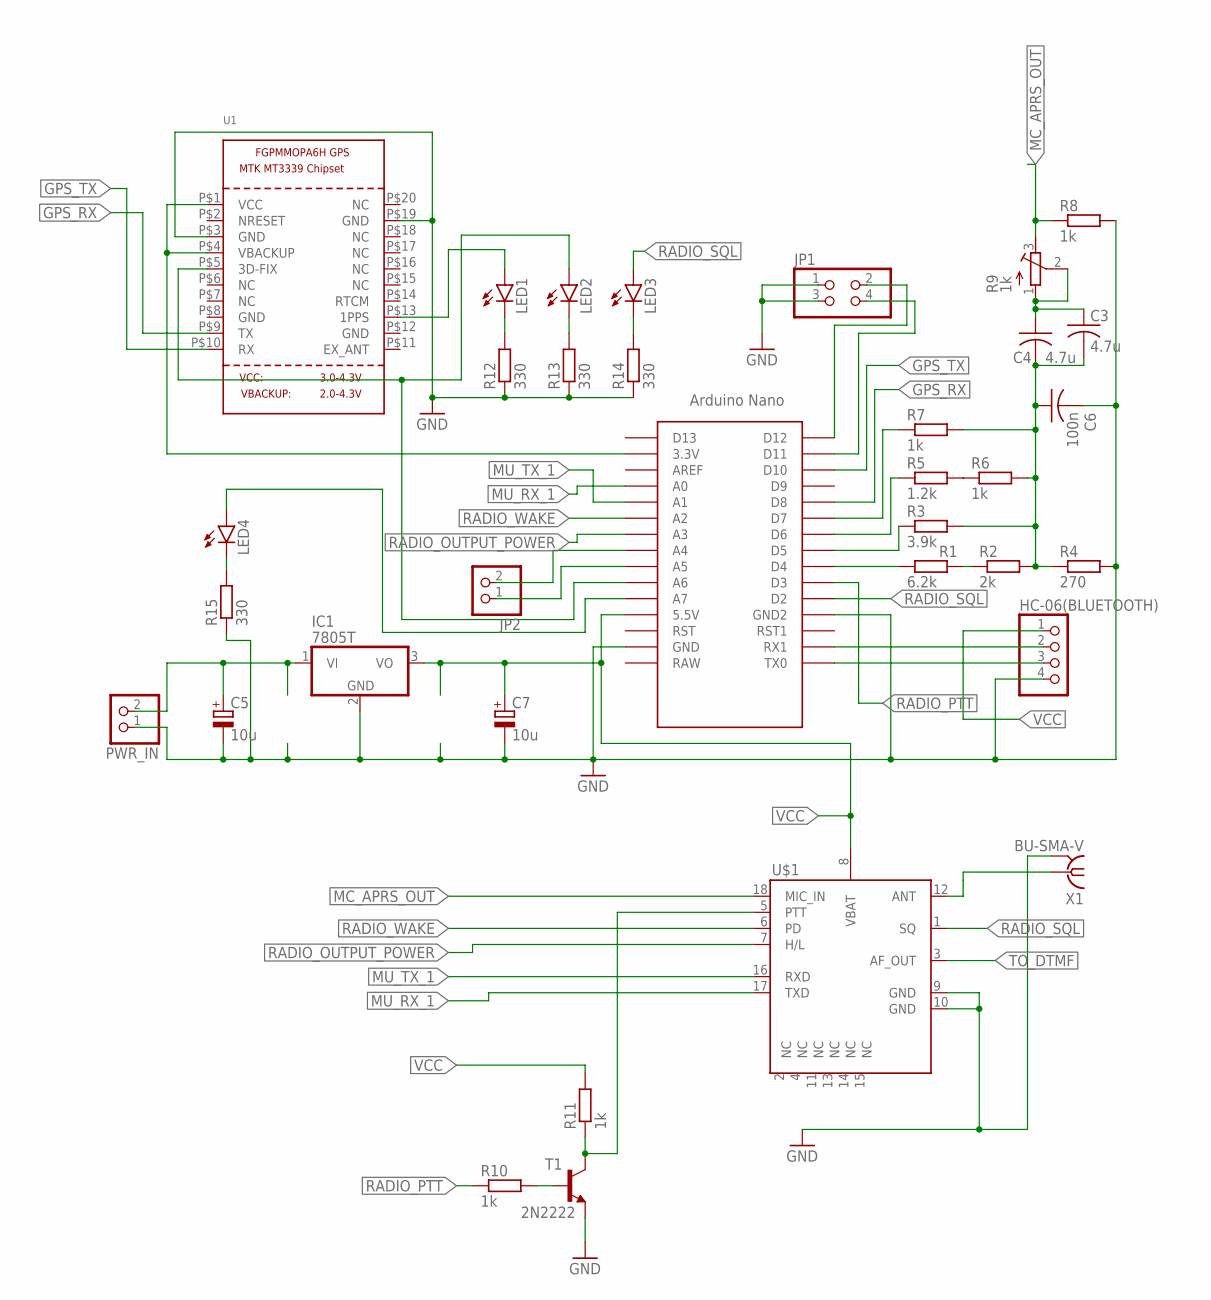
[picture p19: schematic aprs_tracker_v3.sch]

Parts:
C3: 4.7u; C050-024X044
C4: 4.7u; C1206
C5, C7: 10u; E5-6
C6: 100n; C050-024X044
HC-06(BLUETOOTH): PINHD-1X4; 1X04
IC1: 7805T; TO220H
JP1: PINHD-2X2; 2X02
JP2: PINHD-1X2; 1X02
LED1, LED2, LED3, LED4: LEDCHIP-LED0805; CHIP-LED0805
PWR_IN: PINHD-1X2; 1X02
R1: 6.2k; 0207/7
R2: 2k; 0207/7
R3: 3.9k; 0207/7
R4: 270; 0204/7
R5: 1.2k; 0207/7
R6, R7, R8, R10, R11: 1k; 0207/7
R9: 1k; RTRIM3339P
R12, R13, R14, R15: 330; R0805
T1: 2N2222; TO92-EBC-OVAL
U1: GPS_FGPMMOPA6H; FGPMMOPA6H
U$1: DRA818A
U$4: NANO-2; NANO-NOICSP
X1: BU-SMA-V

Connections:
GND: C5.-, C6.2, C7.-, HC-06(BLUETOOTH).4, IC1.2 (GND), JP1.1, JP1.3, PWR_IN.1, R4.2, R8.2, R12.1, R13.1, R14.1, R15.1, T1.E, U1.P$3 (GND), U1.P$19 (GND), U$1.9 (GND), U$1.10 (GND), U$4.GND, U$4.GND1 (GND2), X1.2, X1.3 (2), X1.4 (2), X1.5 (2)
GPS_RX: U1.P$9 (TX), U$4.D8
GPS_TX: U1.P$10 (RX), U$4.D10
MC_APRS_OUT: R8.1, R9.3 (E), U$1.18 (MIC_IN)
MU_RX_1: U$1.17 (TXD), U$4.A0
MU_TX_1: U$1.16 (RXD), U$4.A1
unnamed: U$1.12 (ANT), X1.1
unnamed: C5.+, IC1.1 (VI), PWR_IN.2
unnamed: HC-06(BLUETOOTH).2, U$4.RX1
unnamed: R1.1, U$4.D4
unnamed: R3.1, U$4.D5
unnamed: R5.1, U$4.D6
unnamed: R7.1, U$4.D7
unnamed: R1.2, R2.1
unnamed: R5.2, R6.1
unnamed: C3.2, C4.2, C6.1, R2.2, R3.2, R4.1, R6.2, R7.2
unnamed: C3.1, C4.1, R9.1 (A), R9.2 (S)
unnamed: R11.1, T1.C, U$1.5 (PTT)
unnamed: HC-06(BLUETOOTH).3, U$4.TX0
unnamed: R10.2, T1.B
unnamed: JP1.2, U$4.D12
unnamed: JP1.4, U$4.D11
unnamed: JP2.1, U$4.A5
unnamed: JP2.2, U$4.A4
unnamed: U1.P$1 (VCC), U1.P$4 (VBACKUP), U$4.3.3V
unnamed: LED1.C, R12.2
unnamed: LED2.C, R13.2
unnamed: LED3.C, R14.2
unnamed: LED1.A, U1.P$13 (1PPS)
unnamed: LED4.C, R15.2
unnamed: LED4.A, U$4.A7
unnamed: LED2.A, U1.P$5 (3D-FIX), U$4.A6
RADIO_OUTPUT_POWER: U$1.7 (H/L), U$4.A3
RADIO_PTT: R10.1, U$4.D3
RADIO_SQL: LED3.A, U$1.1 (SQ), U$4.D2
RADIO_WAKE: U$1.6 (PD), U$4.A2
TO_DTMF: U$1.3 (AF_OUT)
VCC: C7.+, HC-06(BLUETOOTH).1, IC1.3 (VO), R11.2, U$1.8 (VBAT), U$4.5V (5.5V)

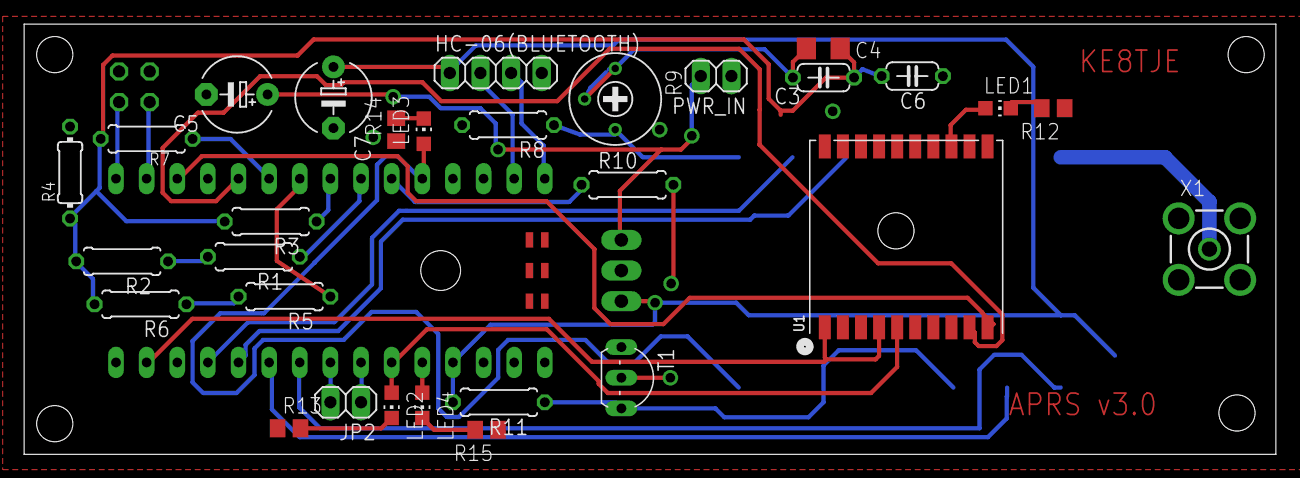
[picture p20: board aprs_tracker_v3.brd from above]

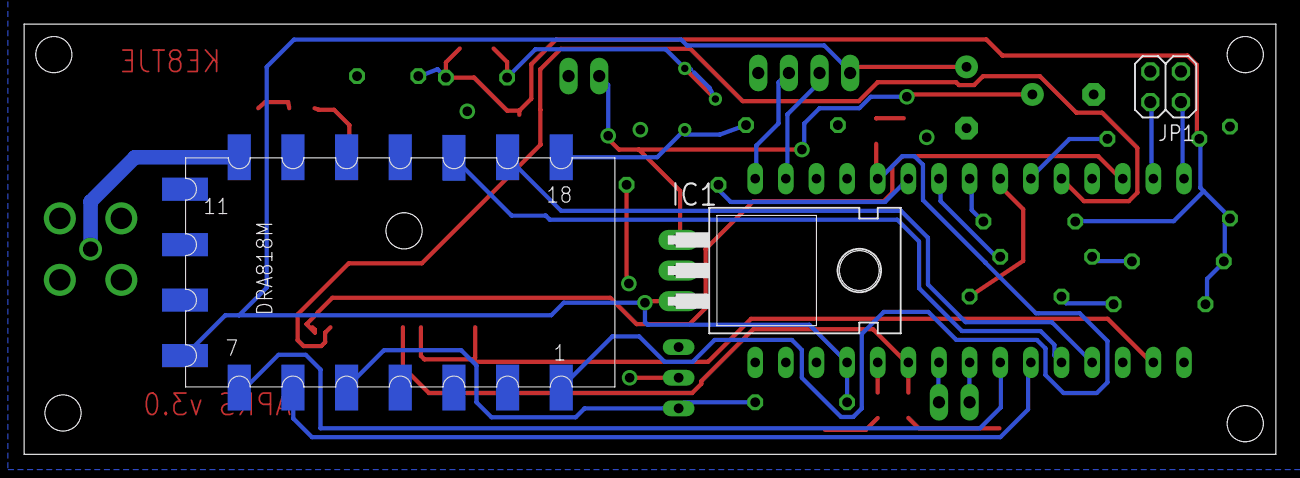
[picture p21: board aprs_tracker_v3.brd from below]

Board: 2 copper layers, 103.8 x 35.7 mm, 34 parts (3 on the bottom side), 37 nets.

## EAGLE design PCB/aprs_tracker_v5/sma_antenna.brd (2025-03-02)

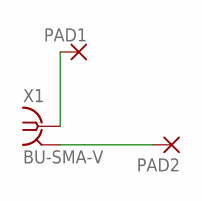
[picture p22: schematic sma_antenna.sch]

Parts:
PAD1, PAD2: 3,81/1,4
X1: BU-SMA-V

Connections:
unnamed: PAD1.1, X1.1
unnamed: PAD2.1, X1.2, X1.3 (2), X1.4 (2), X1.5 (2)

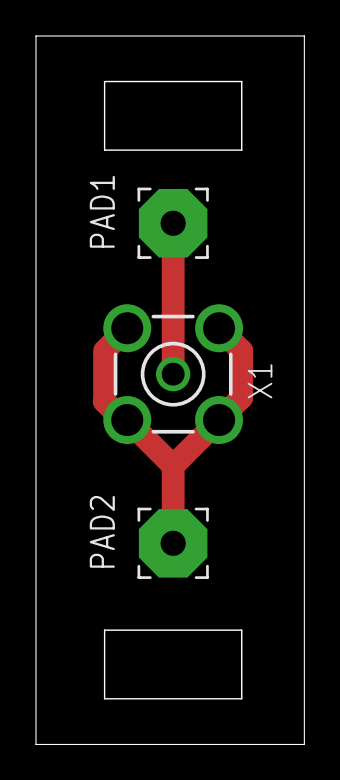
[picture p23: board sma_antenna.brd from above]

Board: 2 copper layers, 14.9 x 39.4 mm, 3 parts (0 on the bottom side), 2 nets.

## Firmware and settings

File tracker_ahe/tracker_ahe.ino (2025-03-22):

#include <stdio.h>
//#include <SoftwareSerial.h>
#include <HardwareSerial.h>
#include "DRA818.h"  // uncomment the following line in DRA818.h (#define DRA818_DEBUG)
#include <LibAPRS_Tracker.h>
#include <Wire.h>


#define ADC_REFERENCE REF_5V
#define OPEN_SQUELCH false

/* Used Pins */
#define radio_wake 16
#define radio_ppt 13  //not needed

#define radio_pwr 17
#define alternate_freq 12
#define radio_sql 2

#define sim_packet 11
#define radio_freq_sw 12

#define RX 14  // arduino serial RX pin to the DRA818 TX pin
#define TX 15  // arduino serial TX pin to the DRA818 RX pin

// old 300
#define timeout 300

#define freq_rx 146.875
#define freq_main 144.390
#define freq_alt 145.390
#define alt_freq_delay 10  //every 10 packets it will switch to alt freq

#define ctcss 146.2

#define simulate 0  // Set to 1 for testing
#define firmware_v 5.2

#define aprs_icon_low 'S'
#define aprs_icon_high 'O'

// Icon - setting:
//APRS_setSymbol('S');
// S - shuttle
// < - Bike
// O - Balloon
// > - car
// $ - phone
// [ - walker

#define aprs_id 11

//9 - Mobile station
//11 - Aircraft/Balloon
//7 - Hand held

#define APRS_TX_offset_utc_sec 19  // this selects what UTC second the packet will be sent out
#define APRS_interval_count 100    // 100 is 1 min


SoftwareSerial *dra_serial;  // Serial connection to DRA818
DRA818 *dra;                 // the DRA object once instanciated

String packetBuffer;
SoftwareSerial gps(8, 10);  // RX, TX


// W8CUL location
char Lat[] = "xxxx.xxxxxx";
char Lon[] = "xxxxx.xxxxxxxx";
char alt[] = "xxxxxxxxxx xxxxxxxxxx xxxxxxxxxx xxxxxxxxxx";  //43 chars
char cmd[20];

char test_data[150];

int cmd_cnt = 0;

int msg_id = 0;
int msg_valid = 0;
int loc_valid = 0;

char myCALL[] = "KE8TJE";
float freq_tx;

float alt_num = 0;

int packet_id = 0;
int radio_freq_change = 0;

int time_trigger = 0;
float lon, lat, utc;

void setup() {

  Serial.begin(57600);  // for logging
  //Wire.begin(0x08);     //added for i2c`:w


  Serial.println("[info] KE8TJE - APRS tracker");
  Serial.print(firmware_v);
  Serial.println("v");
  Serial.println("[info] Pause");
  delay(5000);
  Serial.println("[info] IO init");

  dra_serial = new SoftwareSerial(RX, TX);  // Instantiate the Software Serial Object.
  
  init_radio();
  radio_on();
  set_radio_pwr(1);  // 0 low power

  // afternate frequancy in run time
  if (digitalRead(radio_freq_sw)) {
    freq_tx = freq_main;

  } else {
    freq_tx = freq_alt;
  }
  Serial.print("[info] ");
  Serial.println(freq_tx);
  //start GPS
  gps.begin(9600);

  //init radio module and change frequency

  //dra = DRA818::configure(dra_serial, DRA818_VHF, freq_tx, freq_rx, sql=4, vol=8, 0, 0, DRA818_12K5, true, true, true, &Serial);
  dra = DRA818::configure(dra_serial, DRA818_VHF, freq_tx, freq_rx, 5, 8, 0, 0, DRA818_12K5, true, true, true, &Serial);

  if (!dra) {
    Serial.println("[err ] RF init failed");
  } else {
    Serial.println("[info] RF OK");
  }
}

void loop() {

  //$GNGGA,033145.000,3938.0803,N,07957.1891,W,1,09,1.05,293.2,M,-33.0,M,,*4D
  gps.listen();
  while (gps.available() > 0) {
    String gps_raw = gps.readStringUntil('\n');
    //Serial.println(gps_raw);
    // Valid data: $GPGLL,3938.28486,N,07957.13511,W,191757.00,A,A*7D
    if (gps_raw.substring(0, 6) == "$GNGGA") {
      Serial.println(gps_raw);
      gps_raw.toCharArray(test_data, 100);
      char *p = strtok(test_data, ",");
      update_GPS_v2(p);
    }
  }
}

void update_GPS_v2(char *p) {

  // V2 - Packet
  // $GPGLL,3927.83254,N,0808.25462,W,130448.00,A,A*71

  // V3 - Packet
  // $GNRMC,134055.000,A,3509.7572,N,09010.4938,W,1.51,338.00,121023,,,A*6C
  // V3 +
  // $GNGGA ,033145.000 ,3938.0803  ,N      ,07957.1891 ,W        ,1  ,09 ,1.05 ,293.2,M,-33.0,M,,*4D
  //  <>    ,<1>        ,<2lat>     ,<3latd> ,<4lon>    ,<5lond>  ,<6>,<7>,<8>  ,<9>  ,<10>  
  p = strtok(NULL, ",");  //time
  utc = atof(p);

  int sec = long(utc) % 100;
  int min = long(utc) % 10000 - sec;
  Serial.print(min);
  Serial.print(",");
  Serial.println(sec);

  p = strtok(NULL, ",");  //lat - <2>
  sprintf(Lat, "%s", p);

  // bug fix in v2
  if (Lat[4] == '.') {
    Lat[7] = '\0';
  } else {
    Lat[8] = '\0';
  }
  p = strtok(NULL, ",");  // lat_char - <3>
  sprintf(Lat, "%s%s\0", Lat, p);

  p = strtok(NULL, ",");  //lng - <4>
  sprintf(Lon, "%s", p);
  if (Lon[4] == '.') {
    Lon[7] = '\0';
  } else {
    Lon[8] = '\0';
  }

  p = strtok(NULL, ",");  //dir - <5>
  sprintf(Lon, "%s%s\0", Lon, p);

  p = strtok(NULL, ",");  //state - <6>
  //Serial.print("-");
  //Serial.println(p);

  if (p[0] >= '1' & p[0] <= '4') {
    msg_valid = 1;
  } else {
    //Serial.println("[!] Invalid data");
    msg_valid = 0;
    return;
  }
  p = strtok(NULL, ",");
  p = strtok(NULL, ",");
  p = strtok(NULL, ","); //<9> alt
  alt_num = atof(p);

 
  if (sec == APRS_TX_offset_utc_sec & (min % APRS_interval_count) == 0 & msg_valid) {
    Serial.println("[i] Event trigger");
    gps.stopListening();
    //delay(5000);
    location_update();
    msg_valid = 0;
    gps.listen();
  }

}


int location_update() {

  // stop transmitting on a busy channel

  // setting radio to low power for high altitude
  if (alt_num > 7000) {
    APRS_setSymbol(aprs_icon_low);
    set_radio_pwr(0);
  } else {
    APRS_setSymbol(aprs_icon_high);
    set_radio_pwr(1);
  }

  //radio_TX();
  Serial.println("[info] APRS:start");

  APRS_init();

  APRS_setPreamble(400);

  APRS_setCallsign(myCALL, aprs_id);
  APRS_setLat(Lat);
  APRS_setLon(Lon);
  int alt_km = int(alt_num)/1000;
  int alt_sub_1k = int(int(alt_num)%1000)/10;

  if(packet_id==999) packet_id=0; //reset counter for telemetry

  char comment[30];
  //delay(100);
  sprintf(alt, "#T%03d,%d,%d",packet_id++,alt_km,alt_sub_1k);
  APRS_sendLoc(alt, strlen(alt), ' ');
  

  while(bitRead(PORTB,5)); //lock untill packet is sent
  delay(800);
  Serial.println("[info] APRS:end");
  msg_valid = 0;

}

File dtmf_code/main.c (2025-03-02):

#define F_CPU 1000000

#include <avr/io.h>
#include <util/delay.h>
//#include "i2c_primary.c"

#include <stdint.h>            // has to be added to use uint8_t
#include <avr/interrupt.h>    // Needed to use interrupts

#include "USI_TWI_Master.c" 
//#include "old/i2c.c"

char cmd=0;

char cmds[20];
char cmd_no=0;

char cmd_str[4] ={7,8,9,12};
int cmd_match=1;

int main(void) {

//initialization to check if program mode is on

#define SLAVE_APRS 0x08
//#define debug 1


if(PINA & _BV(PA7)){
	while(1){
		//DELAY LOOP FOR PROGRAMMING
		//All external devices are disabled
		
		//slow blink - programming mode	
		PORTA |= _BV(PA7);
		_delay_ms(500);
 
		PORTA &= ~_BV(PA7);
	 	_delay_ms(500);
	}
}

// normal program
	 
	init_io(); 
	sei();

	//i2c test
	
	while(1){	

//	send_i2c_data(65,SLAVE_APRS);


	if(cmd){
			cmds[cmd_no++] = cmd; //store cmds
			#ifdef debug
				send_i2c_data(cmd+100,SLAVE_APRS); //debug
			#endif
			if(cmd==12 | cmd_no>19){
				
				cmd_match = 1;
				int i;
				for(i=0;i<cmd_no;i++){
					send_i2c_data(cmds[i],SLAVE_APRS); //debug
					
					if(!(cmds[i]==cmd_str[i]))
						cmd_match = 0;
				}
				if(cmd_match){
					cutdown();
				}
				cmd_no = 0;
			}
			cmd = 0;
	}
	
#ifdef debug
		PORTA |= _BV(PA7);
		_delay_ms(50);
 
		PORTA &= ~_BV(PA7);
	 	_delay_ms(50);
#endif

#ifndef debug
	_delay_ms(100);
#endif

	} 
 return 0;
}




void init_io(){

//LED indicator - removed (low voltage detected)

// input pins from DTMF
// PA0,PA1,PA2,PA3
// PB2 - tone precent pin.

//PA5 - Cutdown
//PA7 - Drouge 

DDRA |= _BV(PA7) | _BV(PA5);

// input 

// INT0 interrupt pin

//MCUCR |= (1<< ISC01) | (1<<ISC00); // rising edge
MCUCR |= (1<< ISC01); // falling edge
GIMSK |= (1<<INT0);
SREG |= (1<<7);

USI_TWI_Master_Initialise();

}



ISR(INT0_vect){

	cmd = PINA & 0x0f;	
}

//i2c function

void send_i2c_data(char data,char address){

	unsigned char const tempUSISR_8bit = (1<<USISIF)|(1<<USIOIF)|(1<<USIPF)|(1<<USIDC)|      // Prepare register value to: Clear flags, and
                                 (0x0<<USICNT0);                                     // set USI to shift 8 bits i.e. count 16 clock edges.
  unsigned char const tempUSISR_1bit = (1<<USISIF)|(1<<USIOIF)|(1<<USIPF)|(1<<USIDC)|      // Prepare register value to: Clear flags, and
                                 (0xE<<USICNT0); 									// set USI to shift 1 bit i.e. count 2 clock edges.
	
	USI_TWI_Master_Start();
	USIDR = address<<1|0;
	USI_TWI_Master_Transfer(tempUSISR_8bit);
	USI_TWI_Master_Transfer(tempUSISR_1bit);
	USIDR = data;
	USI_TWI_Master_Transfer(tempUSISR_8bit);
	USI_TWI_Master_Transfer(tempUSISR_1bit);
	USI_TWI_Master_Stop();

}


void cutdown(){
	// cutdown sequence
	for(int i=0;i<20;i++){

		PORTA |= _BV(PA5);
		_delay_ms(100);
#ifndef debug
		PORTA &= ~_BV(PA5);
	 	_delay_ms(100);
#endif
	}

	//turn off mosfet
	PORTA &= ~_BV(PA5);
	_delay_ms(100);

}

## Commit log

2023-05-14 final version before the ground test
2023-05-14 updated the documentation and final fixes to a msg valid flag for GPS data
    [radio.ino, tracker_ahe.ino]
2023-05-17 added simulation preproc commands and better serial prints
2023-05-18 Bug fix on the memory error
    [tracker_ahe.ino]
2023-07-06 Added v2.2 PCB
    [aprs_v2.2.brd, aprs_v2.2.sch]
2023-07-06 added v2.2 PCB and readme updates
2023-07-06 added doc pcb image
2023-07-14 added changes to have one jumper always in the selection switches
2023-08-19 added altitude and horizontal error
    [tracker_ahe.ino]
2023-10-01 added YAAC logs from 10/01 launch
    [Recovery-Direct_APRSAX25rcvd-2023-10-01.csv]
2023-10-07 aprs v3.0 inital desin
    [aprs_tracker_v3.brd, aprs_tracker_v3.sch]
2023-10-08 added finalized v3
    [aprs_tracker_v3.brd, aprs_tracker_v3.sch]
2023-10-08 modified documentation to add flight data form 01/10/23
    [aprs_tracker_v3.brd]
2023-10-09 added BOM and final fixes
    [aprs_tracker_v3.brd, aprs_tracker_v3.sch]
2023-10-11 fixed the location update bug
    [tracker_ahe.ino]
2023-10-22 added v3 final code and data processing code
    [flight-300234064701700-2023-10-01.csv]
2023-12-05 added data from TX launch and modifed script for plotting
    [aprsfi_export_KE8TJE-11_20230930_234754_20231001_234754.csv, aprsfi_export_KE8TJE-11_20231013_205022_20231015_205022.csv, flight-300234064701700-2023-10-14.csv]
2023-12-24 added sql interupt - DTMF observations - sql pin is interfaced correctly
    [F0004CH1.CSV, F0004CH2.CSV, F0004CH3.CSV]
2023-12-24 added obsidianmd and new DTMF tone data
    [F0007CH1.CSV, F0007CH2.CSV, F0007CH3.CSV]
2023-12-26 Added DTMF v1.0 board and required libraries for eagle
    [dtmf_v1.brd, dtmf_v1.sch]
2023-12-27 vault backup: 2023-12-27 10:32:53
    [dtmf_v1.brd, dtmf_v1.sch]
2023-12-27 modifications done on mac for the board
    [dtmf_v1.brd, dtmf_v1.sch]
2024-01-01 DTMF v1 completed with cutdown 30x100 mm form factor
    [dtmf_v1.brd, dtmf_v1.sch]
2024-01-04 cleaned the schematic for documentation
    [dtmf_v1.brd, dtmf_v1.sch]
2024-01-06 modified PCB with JLC DRC file
    [dtmf_v1.brd, dtmf_v1.sch]
2024-01-07 added openhw log,slot for internal leds
    [dtmf_v1.brd, dtmf_v1.sch]
2024-01-07 added atmega328p direct board APRS-v4
    [aprs_tracker_v3.brd, aprs_tracker_v3.sch, aprs_tracker_v4.brd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]
2024-01-07 vault backup: 2024-01-07 17:03:22
    [1HZ02.csv, PTER02.csv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]
2024-01-08 final board design
    [dtmf_v1.brd, dtmf_v1.sch]
2024-01-10 completed aprs v4
    [aprs_tracker_v4.brd, aprs_tracker_v4.sch]
2024-01-10 fix 3v regulator location
    [aprs_tracker_v4.brd]
2024-01-25 added basic functions to use i2c
2024-01-27 i2c compatible version - this has bugs. but had correct clocks - when i2c is a good starting point
    [main.c]
2024-01-28 new i2c implementation. the arduino responded to the correct address. But data was not sent. possible ack/nak mismatch
2024-01-28 partially working i2c new function
2024-01-28 working i2c for single byte
2024-01-28 Revert "Dtmf"
    [1HZ02.csv, F0004CH1.CSV, F0004CH2.CSV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]
2024-01-28 added dtmf code form crash
    [USI_TWI_Master.h, main.c]
2024-01-28 added i2c data read for the aprs tracker
2024-01-28 recoverd schematic files
    [aprs_tracker_v3.brd, aprs_tracker_v3.sch, aprs_tracker_v4.brd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]
2024-01-30 recoverd tracker v3 file
    [copper_bottom.gbr, copper_top.gbr, drill_1_16.xln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]
2024-01-30 data folder recovered
    [1HZ02.csv, F0004CH1.CSV, F0004CH2.CSV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]
2024-02-11 tested version for v4 board. atl,main and rx confirmed
2024-02-11 vault backup: 2024-02-11 16:34:21
    [dtmf_v1.2.brd, dtmf_v1.2.sch]
2024-06-27 added 2m dipole adapter
    [sma_antenna.brd, sma_antenna.sch]
2024-12-25 added v5 board
    [aprs_tracker_v5.brd, aprs_tracker_v5.sch]
2024-12-28 added 10k res to the i2c lines
    [aprs_tracker_v5.brd, aprs_tracker_v5.sch]
